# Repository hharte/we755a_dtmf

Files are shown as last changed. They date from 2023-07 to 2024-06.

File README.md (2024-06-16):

# WE 755A PBX DTMF Converter

# Introduction

The Western Electric 755A PBX was designed in 1938 and supports pulse dialing only  This DTMF converter adds support for Touch-Tone dialing.  One DTMF Converter board needs to be installed in each of the three links.  The converter recognizes DTMF digits, and sets the pulse counting relays in the link to the terminal count for the number dialed.  This is not a tone to pulse converter, and operates much faster than one.

The dial plan for the 755A PBX consists of local station extensions 20-29 and 30-39.  Although this PBX supports four trunks, they are not directly accessible by stations; instead, key stations with individual trunk pickup keys are used to select the trunks.

Here is an [introductory video of the 755A PBX in operation](https://www.youtube.com/watch?v=Fxt21lnzOqg).

This project builds upon the [OKI AC125A DTMF Converter](https://github.com/hharte/ac125a_dtmf) designed several years ago.  While the OKI is an electromechanical crossbar PBX similar in some ways to the 755A, the OKI is about 40 years more modern.

# Status

Three boards have been assembled and installed in each of the 755A’s links.  They work as intended for station to station and conference calls.

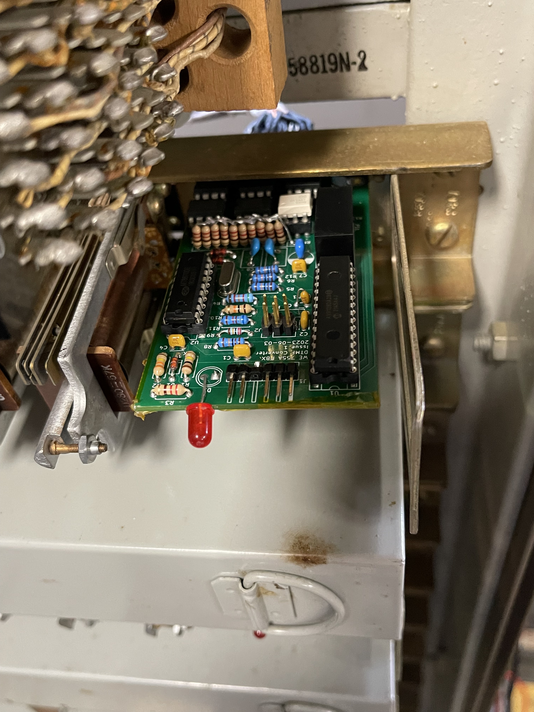
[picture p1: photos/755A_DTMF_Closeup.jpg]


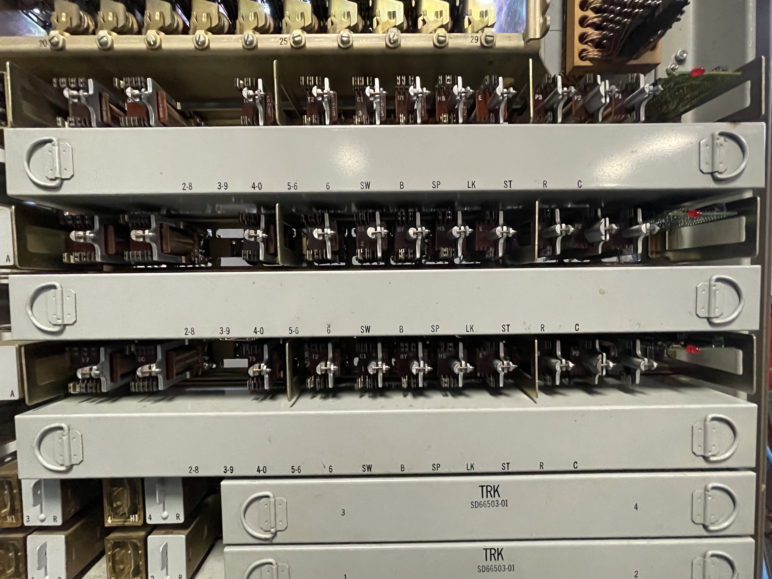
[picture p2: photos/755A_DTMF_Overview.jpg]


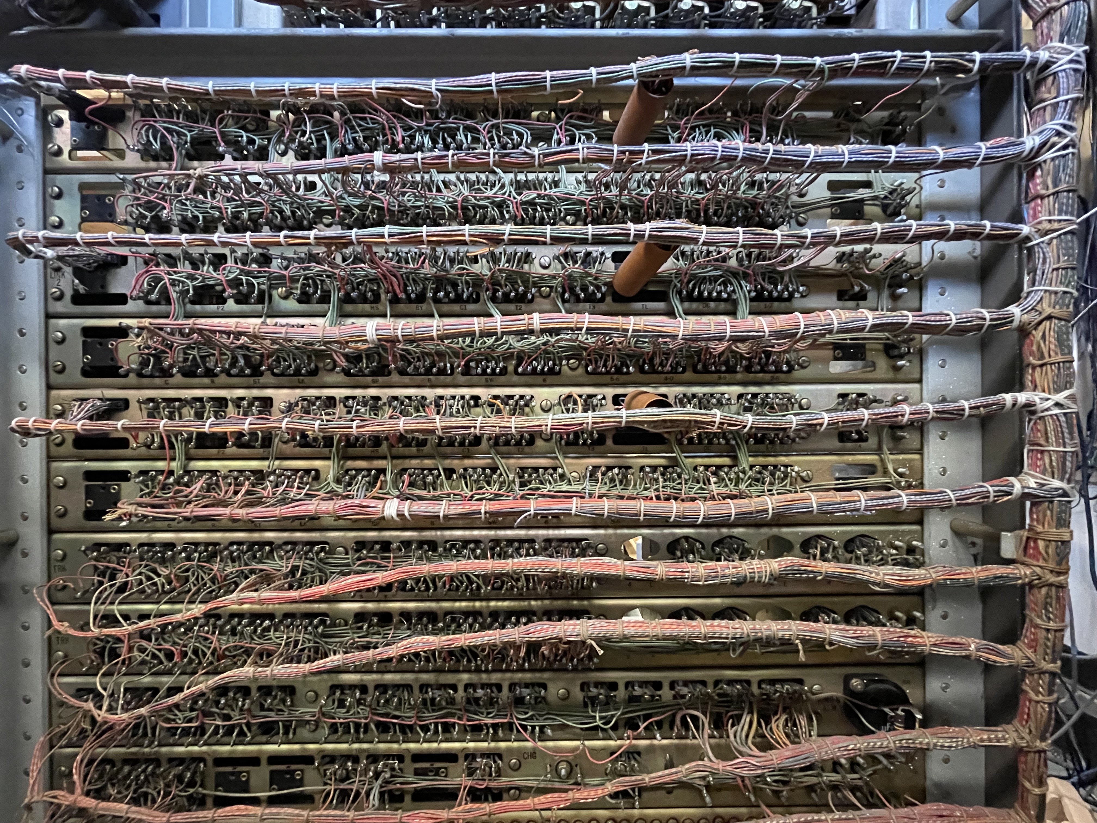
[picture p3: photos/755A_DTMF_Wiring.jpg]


# Translation

The DTMF converter employs digit translation as follows:

<table>
  <tr>
   <td>First Dialed Digit
   </td>
   <td>755A Extension
   </td>
   <td>Description
   </td>
  </tr>
  <tr>
   <td>0
   </td>
   <td>20
   </td>
   <td>Operator
   </td>
  </tr>
  <tr>
   <td>1
   </td>
   <td>-
   </td>
   <td>No operation
   </td>
  </tr>
  <tr>
   <td>2
   </td>
   <td>2x
   </td>
   <td>Direct-dialed 755A stations.
   </td>
  </tr>
  <tr>
   <td>3
   </td>
   <td>3x
   </td>
   <td>Direct-dialed 755A stations.
   </td>
  </tr>
  <tr>
   <td>4, 5, 6, 7
   </td>
   <td>-
   </td>
   <td>No operation
   </td>
  </tr>
  <tr>
   <td>8
   </td>
   <td>26
   </td>
   <td>Ringdown extensions 26, 27.
   </td>
  </tr>
  <tr>
   <td>9
   </td>
   <td>36
   </td>
   <td>Ringdown extensions 36, 37
   </td>
  </tr>
</table>

# 755A PBX Connector

<table>
  <tr>
   <td>Pin
   </td>
   <td>Description
   </td>
   <td>Ribbon Cable Color
   </td>
   <td>Cloth Wire Color
   </td>
   <td>755A Link Connection
   </td>
  </tr>
  <tr>
   <td>1,2
   </td>
   <td>GRD
   </td>
   <td>Brown/Red
   </td>
   <td>Black
   </td>
   <td>Connect to the B relay coil so the converter powers up when the link is active.
   </td>
  </tr>
  <tr>
   <td>3
   </td>
   <td>LINK_SPARE
   </td>
   <td>Orange
   </td>
   <td>
   </td>
   <td>
   </td>
  </tr>
  <tr>
   <td>4
   </td>
   <td>LINK_C1
   </td>
   <td>Yellow
   </td>
   <td>Or/Sl
   </td>
   <td>
   </td>
  </tr>
  <tr>
   <td>5
   </td>
   <td>LINK_6
   </td>
   <td>Green
   </td>
   <td>Sl/W/R
   </td>
   <td>
   </td>
  </tr>
  <tr>
   <td>6
   </td>
   <td>LINK_5-6
   </td>
   <td>Blue
   </td>
   <td>SL/W
   </td>
   <td>
   </td>
  </tr>
  <tr>
   <td>7
   </td>
   <td>LINK_4-0
   </td>
   <td>Violet
   </td>
   <td>Br/R
   </td>
   <td>
   </td>
  </tr>
  <tr>
   <td>8
   </td>
   <td>LINK_3-9
   </td>
   <td>Slate
   </td>
   <td>Br
   </td>
   <td>
   </td>
  </tr>
  <tr>
   <td>9
   </td>
   <td>LINK_2-8
   </td>
   <td>White
   </td>
   <td>Gr/R
   </td>
   <td>
   </td>
  </tr>
  <tr>
   <td>10
   </td>
   <td>LINK_1-7
   </td>
   <td>Black
   </td>
   <td>Gr
   </td>
   <td>
   </td>
  </tr>
  <tr>
   <td>11
   </td>
   <td>LINK_T3
   </td>
   <td>Brown
   </td>
   <td>Or/R
   </td>
   <td>
   </td>
  </tr>
  <tr>
   <td>12
   </td>
   <td>LINK_T2
   </td>
   <td>Red
   </td>
   <td>Or
   </td>
   <td>
   </td>
  </tr>
  <tr>
   <td>13
   </td>
   <td>N/C
   </td>
   <td>Orange
   </td>
   <td>
   </td>
   <td>
   </td>
  </tr>
  <tr>
   <td>14
   </td>
   <td>N/C
   </td>
   <td>Yellow
   </td>
   <td>
   </td>
   <td>
   </td>
  </tr>
  <tr>
   <td>15
   </td>
   <td>N/C
   </td>
   <td>Green
   </td>
   <td>
   </td>
   <td>
   </td>
  </tr>
  <tr>
   <td>16
   </td>
   <td>LINK_E
   </td>
   <td>Blue
   </td>
   <td>Blue
   </td>
   <td>
   </td>
  </tr>
  <tr>
   <td>17
   </td>
   <td>Tip
   </td>
   <td>Violet
   </td>
   <td>O/GR
   </td>
   <td>
   </td>
  </tr>
  <tr>
   <td>18
   </td>
   <td>Ring
   </td>
   <td>Slate
   </td>
   <td>O/GR-R
   </td>
   <td>
   </td>
  </tr>
  <tr>
   <td>19,20
   </td>
   <td>-24VDC
   </td>
   <td>White/Black
   </td>
   <td>Red
   </td>
   <td>-24VDC (Red)
   </td>
  </tr>
</table>

# Connection Notes

From SD-66611-01:

-BAT: Pick up from P1 relay red lead.

GRD: Pick up from B relay coil.

LINK_B: (Blue) Pick up from B relay coil (Upper left terminal.)

Tip: (Violet): Pick up T from 2mF capacitors on lower right corner (looking at from rear):

Ring: (Slate): Pick up T from 2mF capacitors on lower right corner (looking at from rear):

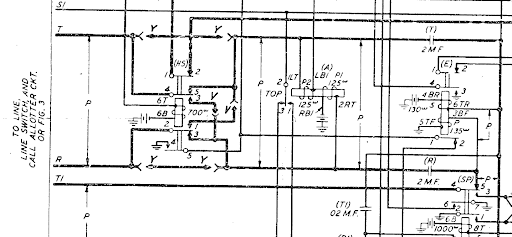
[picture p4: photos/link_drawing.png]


LINK_T2: (Red) Pick up from T2 relay coil.

LINK_T3: (Brown) Pick up from T3 relay coil.

LINK_C1: (Yellow) Pick up from C1 relay coil.

# Technical Details

## Theory of Operation

The 755A DTMF converter’s ground supply is connected to the B relay coil in the link so that the DTMF converter is only powered on when the link is active.  This is necessary so that the first and second digits dialed can be properly identified if the calling station hangs up after dialing only a single digit.

When a station goes off hook, the link allotter selects an idle link, operating the link’s B relay.  This powers up the DTMF converter, which waits for digit(s) to be dialed.  If the first dialed digit is 2 or 3, the converter waits for a second digit to be dialed and then activates the tens and units counting relays to their terminal count.  If the first digit is a digit other than 2 or 3 is dialed, the digit is handled as follows:

* 1, 4, 5, 6, or 7: Ignored
* 0, 8, 9: Translated to a 2-digit extension that is dialed immediately.

After dialing is complete, further dialing is disabled until the called station answers and hangs up again.  This is needed to prevent operation of the pulse counting relays during an established call, while also supporting conference calling.

Conference calling with the 755A works as follows:

1. The originating station calls an extension.
2. The extension answers the call, activating the E relay.
3. The originating station asks the answering station to hang up momentarily so that a conference call can be established.
4. After the called station hangs up, the originating station dials the number of an additional station to join the conference.
5. After the first digit of the called number is dialed, 

## Pulse Dialing Terminal Count Relays

### Tens Digit (2 or 3)

<table>
  <tr>
   <td>Digit
   </td>
   <td>Relays Activated
   </td>
   <td>Note
   </td>
  </tr>
  <tr>
   <td>2
   </td>
   <td>T2
   </td>
   <td>T2 activated stops dialtone.
   </td>
  </tr>
  <tr>
   <td>3
   </td>
   <td>T2 and T3
   </td>
   <td>
   </td>
  </tr>
</table>

### Units Digit (0-9)

<table>
  <tr>
   <td>Digit
   </td>
   <td>Relays Activated
   </td>
   <td>To finish dialing
   </td>
  </tr>
  <tr>
   <td>1
   </td>
   <td>C1, 1-7
   </td>
   <td>Release C1
   </td>
  </tr>
  <tr>
   <td>2
   </td>
   <td>C1, 2-8
   </td>
   <td>Release C1
   </td>
  </tr>
  <tr>
   <td>3
   </td>
   <td>C1, 3-9
   </td>
   <td>Release C1
   </td>
  </tr>
  <tr>
   <td>4
   </td>
   <td>C1, 4-0
   </td>
   <td>Release C1
   </td>
  </tr>
  <tr>
   <td>5
   </td>
   <td>C1, 5-6
   </td>
   <td>Release C1
   </td>
  </tr>
  <tr>
   <td>6
   </td>
   <td>C1, 5-6, 6
   </td>
   <td>Release C1
   </td>
  </tr>
  <tr>
   <td>7
   </td>
   <td>C1, 1-7, 6
   </td>
   <td>Release C1
   </td>
  </tr>
  <tr>
   <td>8
   </td>
   <td>C1, 2-8, 6
   </td>
   <td>Release C1
   </td>
  </tr>
  <tr>
   <td>9
   </td>
   <td>C1, 3-9, 6
   </td>
   <td>Release C1
   </td>
  </tr>
  <tr>
   <td>0
   </td>
   <td>C1, 4-0, 6
   </td>
   <td>Release C1
   </td>
  </tr>
</table>

## Inputs from 755A

<table>
  <tr>
   <td>T
   </td>
   <td colspan="3" >Tip
   </td>
  </tr>
  <tr>
   <td>R
   </td>
   <td colspan="3" >Ring
   </td>
  </tr>
  <tr>
   <td>E
   </td>
   <td colspan="3" >Call Active (Interrupt the microcontroller.)
   </td>
  </tr>
</table>

## Outputs to 755A

<table>
  <tr>
   <td>T2
   </td>
   <td colspan="3" >Tens Digit 2 (Breaks dial tone.)
   </td>
  </tr>
  <tr>
   <td>T3
   </td>
   <td colspan="3" >Tens Digit 3 (Also requires T2 activated.)
   </td>
  </tr>
  <tr>
   <td>1-7, 2-8, 3-9, 4-0, 5-6, 6
   </td>
   <td colspan="3" >Units Digit Selection
   </td>
  </tr>
  <tr>
   <td>C1
   </td>
   <td colspan="3" >Activated before Units selection relays are set, released when the digit is complete.
   </td>
  </tr>
</table>

## MT8870 DTMF Converter Outputs

<table>
  <tr>
   <td>Q3:0
   </td>
   <td colspan="3" >DTMF Digit Selection
   </td>
  </tr>
  <tr>
   <td>StB
   </td>
   <td colspan="3" >DTMF Valid Strobe (Interrupt to microcontroller.)
   </td>
  </tr>
</table>

## Bill of Materials

Online [DigiKey BOM](https://www.digikey.com/en/mylists/list/MP3JW7CHBF).  [Interactive BOM](https://html-preview.github.io/?url=https://github.com/hharte/we755a_dtmf/blob/main/hardware/bom/ibom.html).

<table>
  <tr>
   <td>Quantity
   </td>
   <td>Reference Designator
   </td>
   <td>Value
   </td>
  </tr>
  <tr>
   <td>4
   </td>
   <td>C1, C2, C4, C7
   </td>
   <td>0.1uF
   </td>
  </tr>
  <tr>
   <td>1
   </td>
   <td>C3
   </td>
   <td>0.01uF
   </td>
  </tr>
  <tr>
   <td>2
   </td>
   <td>C5, C8
   </td>
   <td>0.01uF/630V
   </td>
  </tr>
  <tr>
   <td>1
   </td>
   <td>C6
   </td>
   <td>10uF 25V
   </td>
  </tr>
  <tr>
   <td>1
   </td>
   <td>D1
   </td>
   <td>1N4148
   </td>
  </tr>
  <tr>
   <td>1
   </td>
   <td>D2
   </td>
   <td>LED
   </td>
  </tr>
  <tr>
   <td>2
   </td>
   <td>D3, D4
   </td>
   <td>1N4734A
   </td>
  </tr>
  <tr>
   <td>2
   </td>
   <td>F1, F2
   </td>
   <td>Fuse 630mA
   </td>
  </tr>
  <tr>
   <td>2
   </td>
   <td>H1, H2
   </td>
   <td>MountingHole
   </td>
  </tr>
  <tr>
   <td>1
   </td>
   <td>J1
   </td>
   <td>Conn_01x06_Male right angle
   </td>
  </tr>
  <tr>
   <td>1
   </td>
   <td>J2
   </td>
   <td>UPDI (2x3 pin header) Straight
   </td>
  </tr>
  <tr>
   <td>1
   </td>
   <td>J3
   </td>
   <td>Conn_02x10_Odd_Even
   </td>
  </tr>
  <tr>
   <td>1
   </td>
   <td>PS1
   </td>
   <td>SPBW06
   </td>
  </tr>
  <tr>
   <td>1
   </td>
   <td>R1
   </td>
   <td>100K
   </td>
  </tr>
  <tr>
   <td>1
   </td>
   <td>R2
   </td>
   <td>330K
   </td>
  </tr>
  <tr>
   <td>1
   </td>
   <td>R3
   </td>
   <td>220
   </td>
  </tr>
  <tr>
   <td>1
   </td>
   <td>R4
   </td>
   <td>52.3K 1%
   </td>
  </tr>
  <tr>
   <td>4
   </td>
   <td>R5, R6, R8, R12
   </td>
   <td>110K 1%
   </td>
  </tr>
  <tr>
   <td>1
   </td>
   <td>R7
   </td>
   <td>4.7K
   </td>
  </tr>
  <tr>
   <td>1
   </td>
   <td>R9
   </td>
   <td>220K 1%
   </td>
  </tr>
  <tr>
   <td>1
   </td>
   <td>R10
   </td>
   <td>10K
   </td>
  </tr>
  <tr>
   <td>1
   </td>
   <td>R11
   </td>
   <td>68.1K 1%
   </td>
  </tr>
  <tr>
   <td>1
   </td>
   <td>R13
   </td>
   <td>1.5K
   </td>
  </tr>
  <tr>
   <td>1
   </td>
   <td>RN1
   </td>
   <td>220
   </td>
  </tr>
  <tr>
   <td>1
   </td>
   <td>U1
   </td>
   <td>AVR128DA28-I/SP or AVR128DA28-E/SP
   </td>
  </tr>
  <tr>
   <td>1
   </td>
   <td>U2
   </td>
   <td>MT8870
   </td>
  </tr>
  <tr>
   <td>1
   </td>
   <td>U3
   </td>
   <td>H11AA1
   </td>
  </tr>
  <tr>
   <td>5
   </td>
   <td>U4, U5, U6, U7, U8
   </td>
   <td>LAA108 (or LAA110L or CLA170)
   </td>
  </tr>
  <tr>
   <td>1
   </td>
   <td>Y2
   </td>
   <td>3.579545MHZ
   </td>
  </tr>
</table>

## Arduino AVD128DA28 Configuration

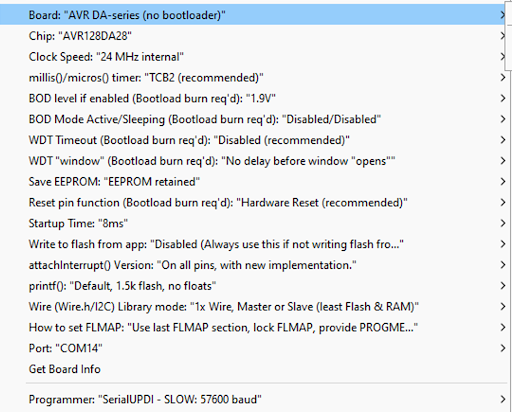
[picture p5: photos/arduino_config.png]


# Other WE 755A Projects

[WE 755A Power Supply](https://github.com/hharte/we755a_ps)

[WE 755A Station Line Concentrator](https://github.com/hharte/we755a_slc)

[WE 755A PBX Monitor](https://github.com/hharte/we755a_mon)

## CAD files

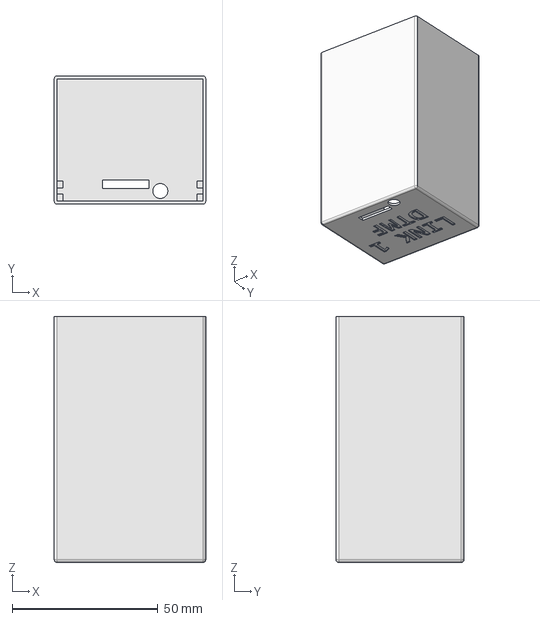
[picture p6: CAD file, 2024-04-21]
enclosure/we755a_dtmf_cover.FCStd
52.0 x 44.0 x 84.4 mm

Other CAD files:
enclosure/we755a_dtmf_cover.stl

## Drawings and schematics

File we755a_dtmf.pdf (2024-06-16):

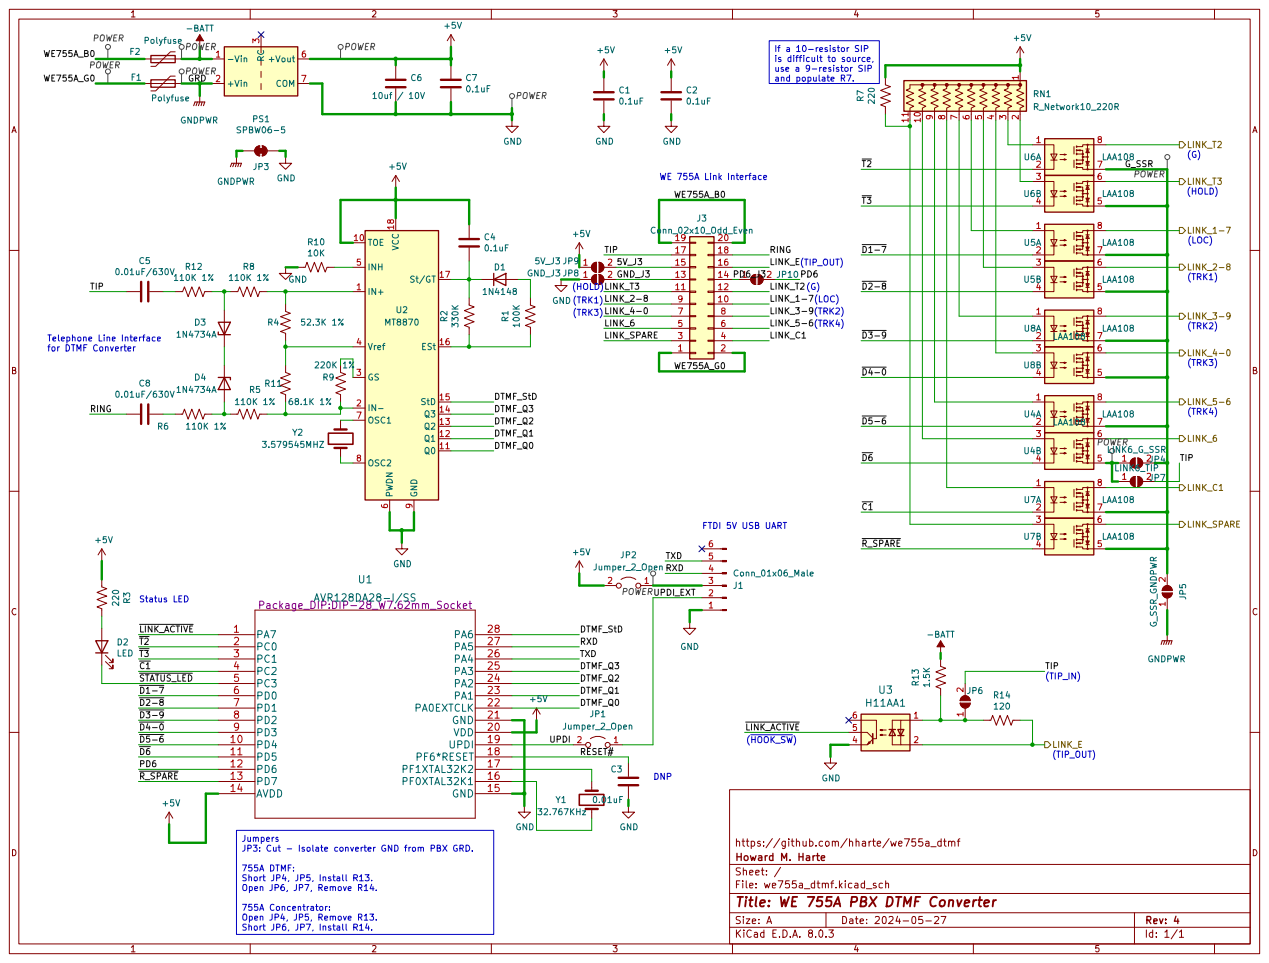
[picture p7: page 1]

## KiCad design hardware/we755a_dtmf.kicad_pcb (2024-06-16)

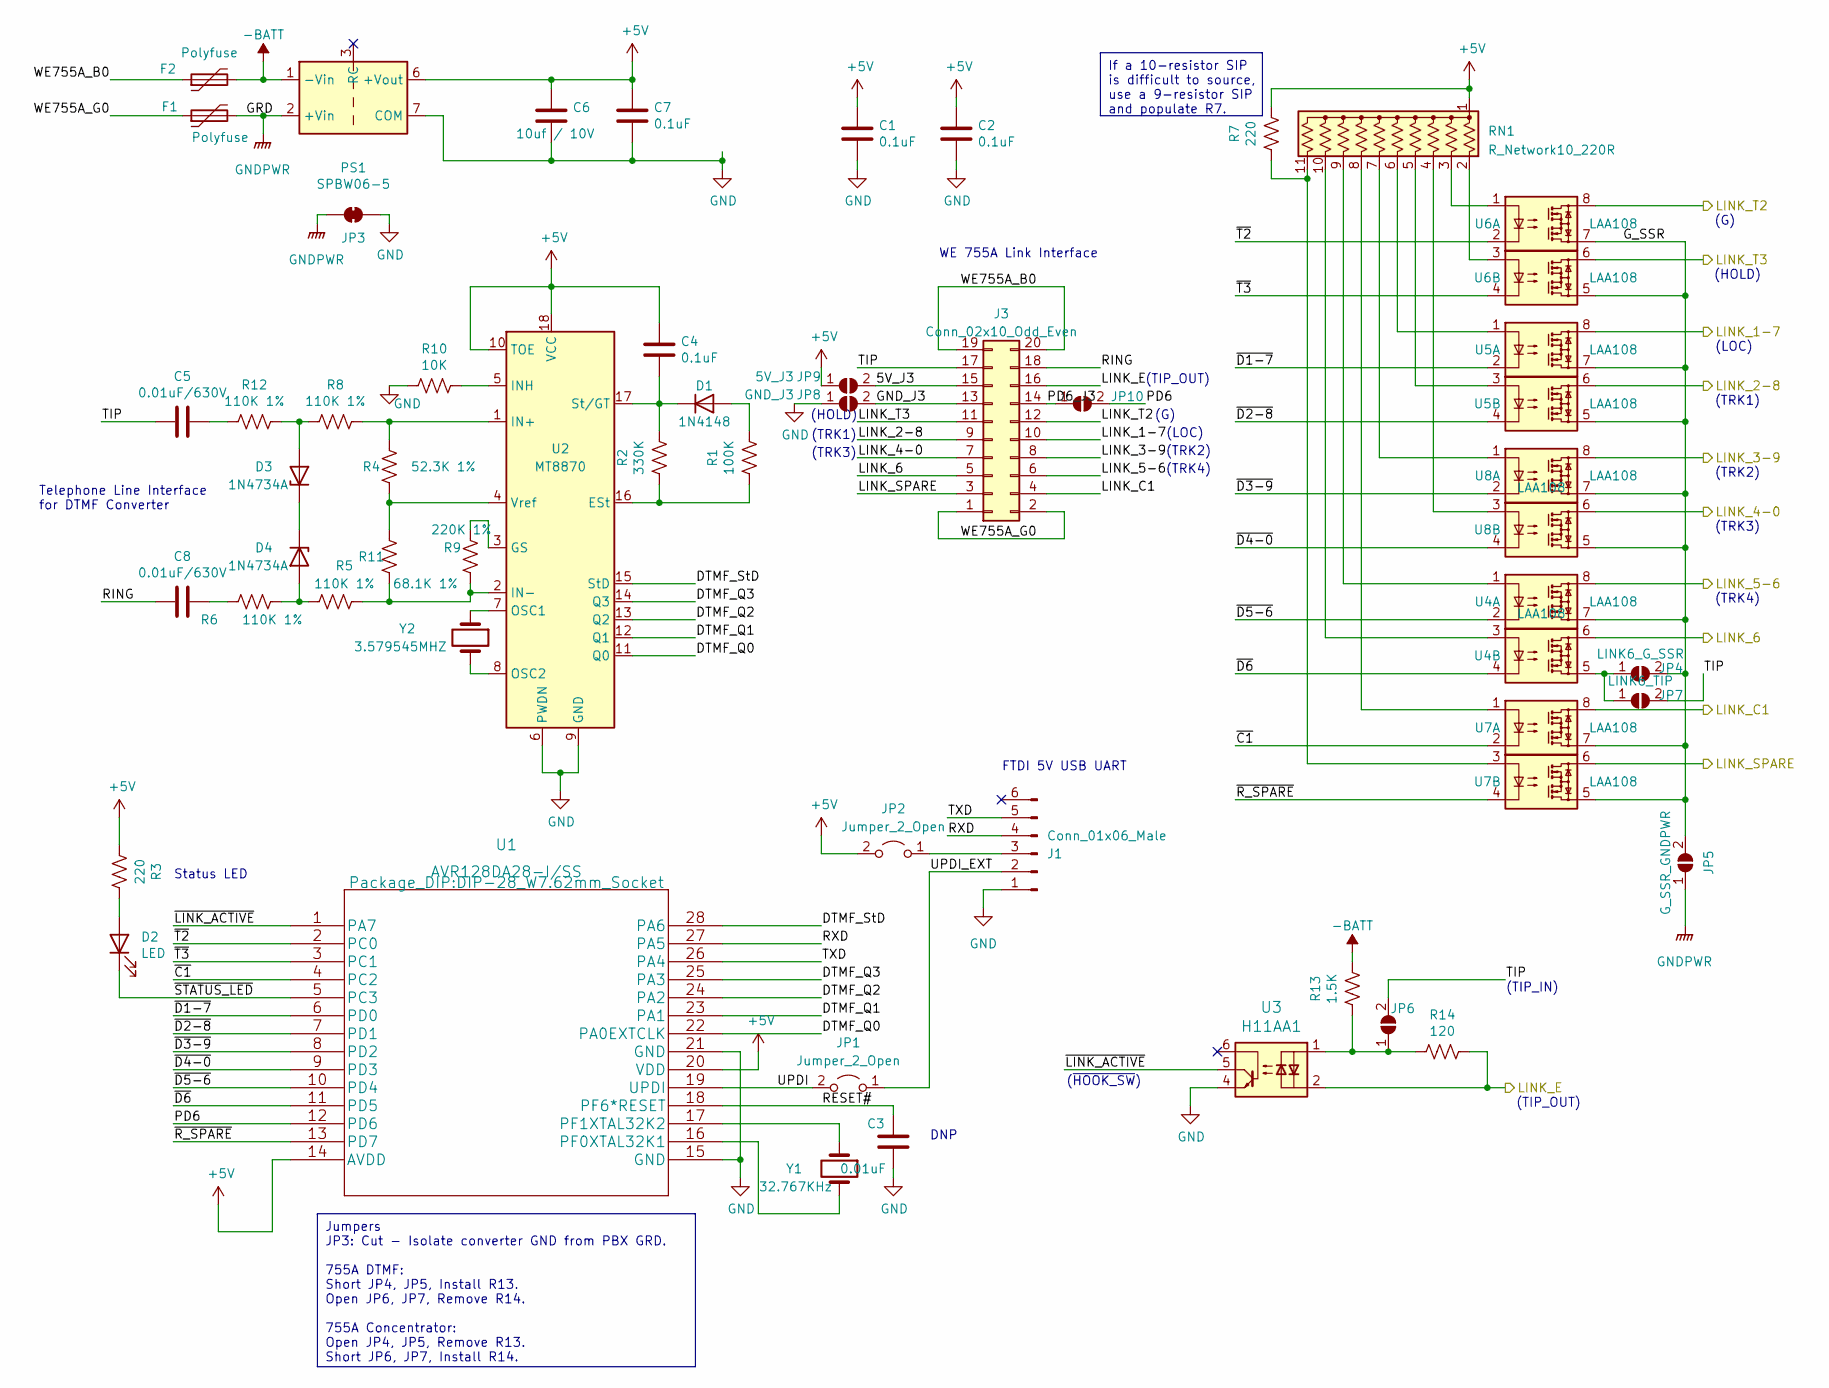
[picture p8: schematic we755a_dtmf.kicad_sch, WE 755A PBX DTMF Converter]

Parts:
C1, C2, C4, C7: 0.1uF; C_Disc_D3.0mm_W2.0mm_P2.50mm; MPN K104M15X7RF5TL2; Digi-Key_PN 56-K104M15X7RF5TL2CT-ND
C3: 0.01uF; C_Disc_D3.0mm_W1.6mm_P2.50mm; MPN K103K15X7RF5UL2; Digi-Key_PN BC5227CT-ND
C5, C8: 0.01uF/630V; C_Disc_D7.5mm_W5.0mm_P5.00mm; MPN RDER72J103K2K1H03B; Digi-Key_PN 490-8927-ND
C6: 10uf / 10V; C_Disc_D5.0mm_W2.5mm_P2.50mm; MPN FG14X7R1A106KRT06; Digi-Key_PN 445-173132-1-ND
D1: 1N4148; D_DO-35_SOD27_P7.62mm_Horizontal; MPN 1N4148TA; Digi-Key_PN 1N4148TACT-ND
D2: LED; LED_D5.0mm; MPN XLUR12D; Digi-Key_PN 1497-1031-ND
D3, D4: 1N4734A; D_DO-41_SOD81_P7.62mm_Horizontal; MPN 1N4734A-T50A; Digi-Key_PN 1N4734A-T50ACT-ND
F1, F2: Polyfuse; FUSE_RXEF025_LTF; MPN RXEF025; Digi-Key_PN RXEF025HF-ND
J1: Conn_01x06_Male; PinHeader_1x06_P2.54mm_Horizontal; MPN 61300611021; Digi-Key_PN 732-5339-ND
J3: Conn_02x10_Odd_Even; WE755A-DTMF; MPN SBH11-PBPC-D10-RA-BK; Digi-Key_PN S9180-ND
JP1, JP2: Jumper_2_Open; PinHeader_1x02_P2.54mm_Vertical
JP3: GRD_TIE; SolderJumper-2_P1.3mm_Bridged_Pad1.0x1.5mm
JP4: LINK6_G_SSR; SolderJumper-2_P1.3mm_Open_Pad1.0x1.5mm
JP5: G_SSR_GNDPWR; SolderJumper-2_P1.3mm_Open_Pad1.0x1.5mm
JP6: TIP_IN; SolderJumper-2_P1.3mm_Open_Pad1.0x1.5mm
JP7: LINK6_TIP; SolderJumper-2_P1.3mm_Open_Pad1.0x1.5mm
JP8: GND_J3; SolderJumper-2_P1.3mm_Open_Pad1.0x1.5mm
JP9, JP10: 5V_J3; SolderJumper-2_P1.3mm_Open_Pad1.0x1.5mm
PS1: SPBW06-5; Converter_DCDC_TRACO_TMR-xxxx_THT; MPN SPBW06G-05; Digi-Key_PN 1866-4814-ND
R1: 100K; R_Axial_DIN0207_L6.3mm_D2.5mm_P7.62mm_Horizontal; MPN CFM12JT100K; Digi-Key_PN S100KHCT-ND
R2: 330K; R_Axial_DIN0207_L6.3mm_D2.5mm_P7.62mm_Horizontal; MPN CFM12JT330K; Digi-Key_PN S330KHCT-ND
R3: 220; R_Axial_DIN0207_L6.3mm_D2.5mm_P7.62mm_Horizontal; MPN CFM14JT220R; Digi-Key_PN S220QCT-ND
R4: 52.3K 1%; R_Axial_DIN0207_L6.3mm_D2.5mm_P7.62mm_Horizontal; MPN MFR-25FBF52-52K3; Digi-Key_PN 52.3KXBK-ND
R5, R6, R8, R12: 110K 1%; R_Axial_DIN0207_L6.3mm_D2.5mm_P7.62mm_Horizontal; MPN MFR-25FBF52-110K; Digi-Key_PN 110KXBK-ND
R7: 220; R_Axial_DIN0204_L3.6mm_D1.6mm_P5.08mm_Horizontal; MPN CFM14JT220R; Digi-Key_PN S220QCT-ND
R9: 220K 1%; R_Axial_DIN0207_L6.3mm_D2.5mm_P7.62mm_Horizontal; MPN MFR-25FBF52-220K; Digi-Key_PN MFR-25FBF52-220K-ND
R10: 10K; R_Axial_DIN0207_L6.3mm_D2.5mm_P7.62mm_Horizontal; MPN CFM12JT10K0; Digi-Key_PN S10KHCT-ND
R11: 68.1K 1%; R_Axial_DIN0207_L6.3mm_D2.5mm_P7.62mm_Horizontal; MPN MFR-25FBF52-68K1; Digi-Key_PN 68.1KXBK-ND
R13: 1.5K; R_Axial_DIN0207_L6.3mm_D2.5mm_P7.62mm_Horizontal; MPN CFM12JT1K50; Digi-Key_PN S1.5KHCT-ND
R14: 120; R_Axial_DIN0207_L6.3mm_D2.5mm_P7.62mm_Horizontal; MPN CFM12JT120R; Digi-Key_PN S120HCT-ND
RN1: R_Network10_220R; R_Array_SIP11; MPN 4611X-101-221LF; Digi-Key_PN 118-4611X-101-221LF-ND
U1: AVR128DA28-I/SS; DIP-28_W7.62mm_Socket; MPN AVR128DA28-E/SP; Digi-Key_PN 150-AVR128DA28-E/SP-ND
U2: MT8870; DIP-18_W7.62mm
U3: H11AA1; DIP-6_W7.62mm; MPN H11AA1; Digi-Key_PN H11AA1M-ND
U4, U5, U6, U7, U8: LAA108; DIP-8_W7.62mm; MPN LAA108; Digi-Key_PN LAA108-ND
Y1: 32.767KHz; Crystal_Round_D2.0mm_Vertical; MPN Do not populate.; Digi-Key_PN Do not populate.
Y2: 3.579545MHZ; Crystal_HC49-U_Vertical; MPN 9B-3.579545MAAJ-B; Digi-Key_PN 887-1000-ND

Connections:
+5V: C1.1, C2.1, C4.2, C6.1, C7.1, JP2.2 (B), JP9.1 (A), PS1.6 (+Vout), R3.2, R7.1, RN1.1 (common), U1.14 (AVDD), U1.20 (VDD), U2.10 (TOE), U2.18 (VCC)
-BATT: F2.2, PS1.1 (-Vin), R13.1
/5V_J3: J3.15, JP9.2 (B)
/DTMF_Q0: U1.22 (PA0EXTCLK), U2.11 (Q0)
/DTMF_Q1: U1.23 (PA1), U2.12 (Q1)
/DTMF_Q2: U1.24 (PA2), U2.13 (Q2)
/DTMF_Q3: U1.25 (PA3), U2.14 (Q3)
/DTMF_StD: U1.28 (PA6), U2.15 (StD)
/GND_J3: J3.13, JP8.2 (B)
/G_SSR: JP4.2 (B), JP5.2 (B), U4.7, U5.5, U5.7, U6.5, U6.7, U7.5, U7.7, U8.5, U8.7
/LINK_1-7: J3.10, U5.8
/LINK_2-8: J3.9, U5.6
/LINK_3-9: J3.8, U8.8
/LINK_4-0: J3.7, U8.6
/LINK_5-6: J3.6, U4.8
/LINK_6: J3.5, U4.6
/LINK_C1: J3.4, U7.8
/LINK_E: J3.16, R14.1, U3.2
/LINK_SPARE: J3.3, U7.6
/LINK_T2: J3.12, U6.8
/LINK_T3: J3.11, U6.6
/PD6: JP10.2 (B), U1.12 (PD6)
/PD6_J3: J3.14, JP10.1 (A)
/RESET#: C3.1, U1.18 (PF6*RESET)
/RING: C8.2, J3.18
/RXD: J1.4, U1.27 (PA5)
/TIP: C5.2, J3.17, JP6.2 (B), JP7.2 (B)
/TXD: J1.5, U1.26 (PA4)
/UPDI: JP1.2 (B), U1.19 (UPDI)
/UPDI_EXT: J1.2, JP1.1 (A)
/WE755A_B0: F2.1, J3.19, J3.20
/WE755A_G0: F1.1, J3.1, J3.2
/~C1: U1.4 (PC2), U7.2
/~D1-7: U1.6 (PD0), U5.2
/~D2-8: U1.7 (PD1), U5.4
/~D3-9: U1.8 (PD2), U8.2
/~D4-0: U1.9 (PD3), U8.4
/~D5-6: U1.10 (PD4), U4.2
/~D6: U1.11 (PD5), U4.4
/~LINK_ACTIVE: U1.1 (PA7), U3.5
/~R_SPARE: U1.13 (PD7), U7.4
/~STATUS_LED: D2.1 (K), U1.5 (PC3)
/~T2: U1.2 (PC0), U6.2
/~T3: U1.3 (PC1), U6.4
GND: C1.2, C2.2, C3.2, C6.2, C7.2, J1.1, JP3.2 (B), JP8.1 (A), PS1.7 (COM), R10.2, U1.15 (GND), U1.21 (GND), U2.6 (PWDN), U2.9 (GND), U3.4
GNDPWR: F1.2, JP3.1 (A), JP5.1 (A), PS1.2 (+Vin)
unnamed: C5.1, R12.2
unnamed: C8.1, R6.2
unnamed: D1.2 (A), R1.1
unnamed: C4.1, D1.1 (K), R2.1, U2.17 (St/GT)
unnamed: D2.2 (A), R3.1
unnamed: D3.2 (A), R8.2, R12.1
unnamed: D3.1 (K), D4.1 (K)
unnamed: D4.2 (A), R5.2, R6.1
unnamed: J1.3, JP2.1 (A)
unnamed: JP4.1 (A), JP7.1 (A), U4.5
unnamed: JP6.1 (A), R13.2, R14.2, U3.1
unnamed: RN1.2 (R1), U6.3
unnamed: RN1.3 (R2), U6.1
unnamed: RN1.4 (R3), U8.3
unnamed: RN1.5 (R4), U5.3
unnamed: RN1.6 (R5), U5.1
unnamed: RN1.7 (R6), U8.1
unnamed: RN1.8 (R7), U7.1
unnamed: RN1.9 (R8), U4.1
unnamed: RN1.10 (R9), U4.3
unnamed: R7.2, RN1.11 (R10), U7.3
unnamed: U1.16 (PF0XTAL32K1), Y1.2
unnamed: U1.17 (PF1XTAL32K2), Y1.1
unnamed: R1.2, R2.2, U2.16 (ESt)
unnamed: R9.1, U2.3 (GS)
unnamed: R4.1, R8.1, U2.1 (IN+)
unnamed: R5.1, R9.2, R11.2, U2.2 (IN-)
unnamed: R10.1, U2.5 (INH)
unnamed: U2.7 (OSC1), Y2.1
unnamed: U2.8 (OSC2), Y2.2
unnamed: R4.2, R11.1, U2.4 (Vref)

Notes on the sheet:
If a 10-resistor SIP is difficult to source, use a 9-resistor SIP and populate R7.
Jumpers JP3: Cut - Isolate converter GND from PBX GRD. 755A DTMF: Short JP4, JP5, Install R13. Open JP6, JP7, Remove R14. 755A Concentrator: Open JP4, JP5, Remove R13. Short JP6, JP7, Install R14.
(HOLD)
FTDI 5V USB UART
Status LED
(~{HOOK_SW})
(TIP_OUT)
(TRK2)
(TRK4)
WE 755A Link Interface
(TIP_IN)
(G)
(TRK1)
DNP
Telephone Line Interface for DTMF Converter
(LOC)
(TRK3)

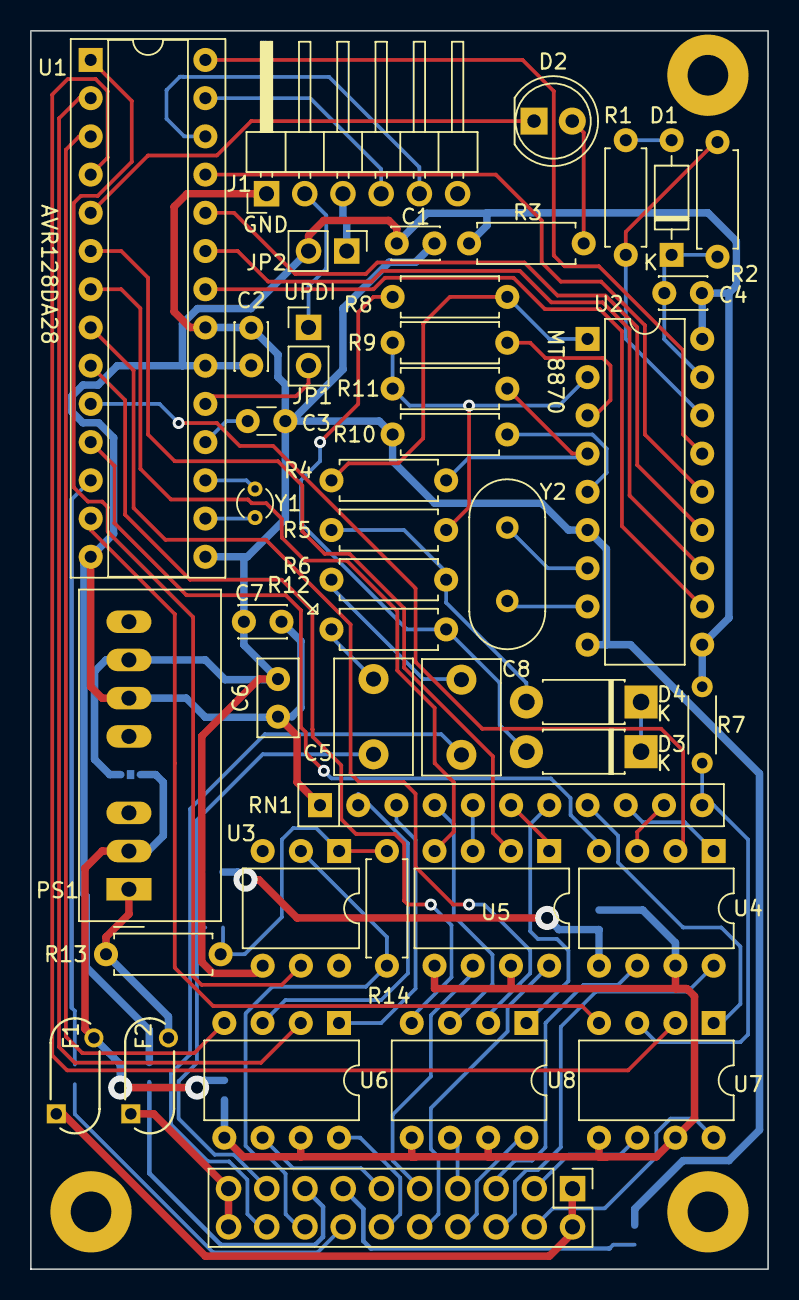
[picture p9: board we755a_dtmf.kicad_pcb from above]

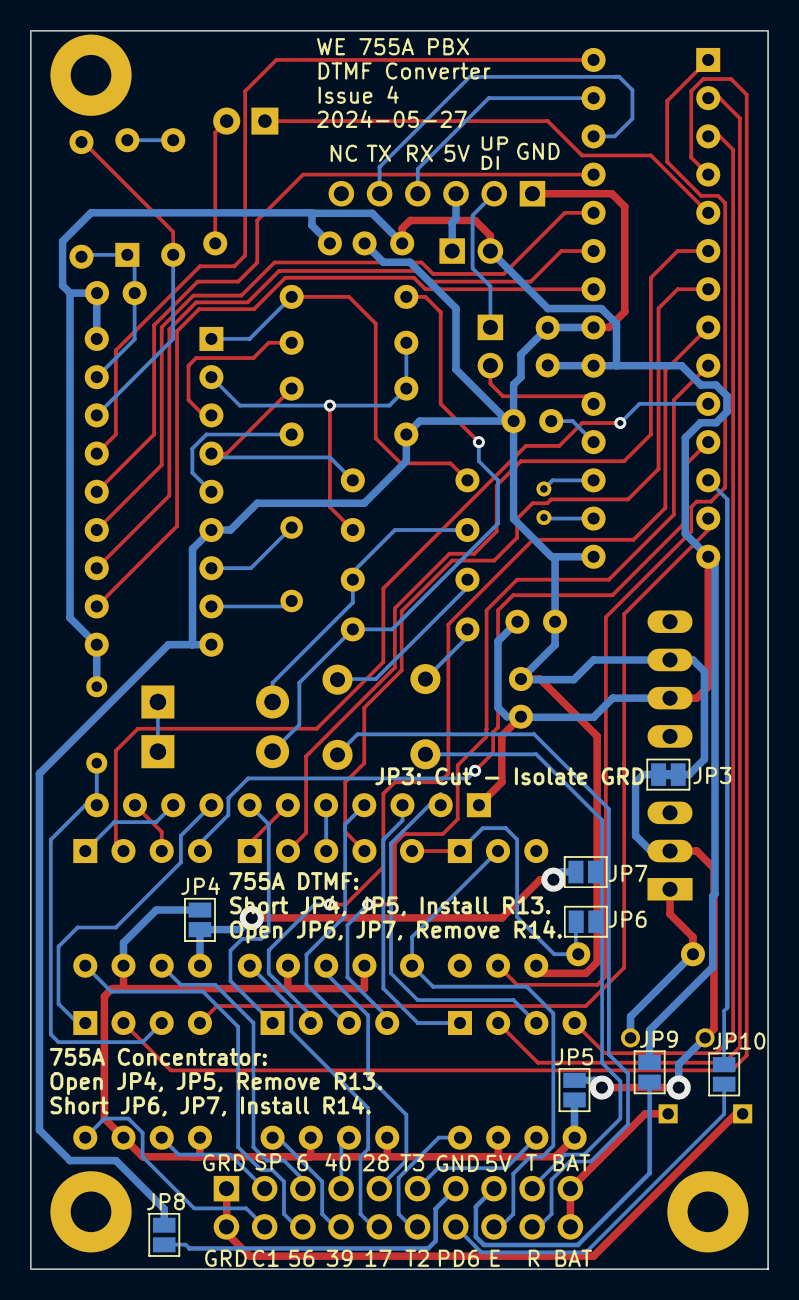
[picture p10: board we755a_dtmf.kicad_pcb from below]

Board: 2 copper layers, 49.0 x 82.3 mm, 52 parts (8 on the bottom side), 77 nets.

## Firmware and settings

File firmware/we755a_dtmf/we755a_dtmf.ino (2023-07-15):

/*************************************************************************
 *                                                                       *
 * Copyright (c) 2023 Howard M. Harte, WZ2Q.                             *
 * https://github.com/hharte/we755a_dtmf                                 *
 *                                                                       *
 * Permission is hereby granted, free of charge, to any person obtaining *
 * a copy of this software and associated documentation files (the       *
 * "Software"), to deal in the Software without restriction, including   *
 * without limitation the rights to use, copy, modify, merge, publish,   *
 * distribute, sublicense, and/or sell copies of the Software, and to    *
 * permit persons to whom the Software is furnished to do so, subject to *
 * the following conditions:                                             *
 *                                                                       *
 * The above copyright notice and this permission notice shall be        *
 * included in all copies or substantial portions of the Software.       *
 *                                                                       *
 * THE SOFTWARE IS PROVIDED "AS IS", WITHOUT WARRANTY OF ANY KIND,       *
 * EXPRESS OR IMPLIED, INCLUDING BUT NOT LIMITED TO THE WARRANTIES OF    *
 * MERCHANTABILITY, FITNESS FOR A PARTICULAR PURPOSE AND                 *
 * NONINFRINGEMENT. IN NO EVENT SHALL HOWARD M. HARTE BE LIABLE FOR ANY  *
 * CLAIM, DAMAGES OR OTHER LIABILITY, WHETHER IN AN ACTION OF CONTRACT,  *
 * TORT OR OTHERWISE, ARISING FROM, OUT OF OR IN CONNECTION WITH THE     *
 * SOFTWARE OR THE USE OR OTHER DEALINGS IN THE SOFTWARE.                *
 *                                                                       *
 * Except as contained in this notice, the name of Howard M. Harte shall *
 * not be used in advertising or otherwise to promote the sale, use or   *
 * other dealings in this Software without prior written authorization   *
 * Howard M. Harte.                                                      *
 *                                                                       *
 * Module Description:                                                   *
 * Western Electric 755A Crossbar PBX DTMF to Pulse Counting Relay       *
 * Converter.                                                            *
 *                                                                       *
 * Receives DTMF digits and activates T2/T3 and pulse counting relays    *
 * to their terminal count for the digit dialed.  This circuit's ground  *
 * comes from the Link B relay so that the converter is powered off when *
 * the link is idle.  This helps discriminate between first and second   *
 * dialed digits.  Additionally, the link E relay is monitored to        *
 * determine when it is ok to allow dialing again for conference calls.  *
 * The Link E relay is activated when the called station answers.  This  *
 * takes the state machine out of DIAL_STATE_DIALING_BLOCKED, returning  *
 * it to DIAL_STATE_IDLE so that further dialing is allowed.  In the     *
 * DIAL_STATE_IDLE state, dialing is inhibited if the E relay is active, *
 * which indicates that the called party is off-hook.                    *
 *                                                                       *
 * Arduino 1.8.57.0 or later with DxCore                                 *
 *                                                                       *
 *************************************************************************/

#define BAUD_RATE           115200
#define MS_PER_TICK         20
#define RELAY_HOLD_MS       100
#define POST_DIAL_MS        100
#define C1_DELAY_MS         60
#define COUNT_PER_MS        93.6
#define RELAY_HOLD_COUNT    (RELAY_HOLD_MS / MS_PER_TICK)
#define POST_DIAL_COUNT     (POST_DIAL_MS / MS_PER_TICK)
#define C1_DELAY_COUNT      (C1_DELAY_MS / MS_PER_TICK)

#define DIAL_STATE_IDLE             0
#define DIAL_STATE_WAIT_DTMF_DONE   1
#define DIAL_STATE_OPERATE_C1       2
#define DIAL_STATE_OPERATE_RELAYS   3
#define DIAL_STATE_DIALING_COMPLETE 4
#define DIAL_STATE_DIALING_BLOCKED  5

/* Pin assignments:
 * ref: https://github.com/SpenceKonde/DxCore/blob/master/megaavr/extras/DA28.md
 */

/* Inputs from MT8870 DTMF Receiver */
#define DTMF_Q0           0   /* PA0 */
#define DTMF_Q1           1   /* PA1 */
#define DTMF_Q2           2   /* PA2 */
#define DTMF_Q3           3   /* PA3 */
#define DTMF_StD          6   /* PA6 */

/* Outputs: Solid-State Relays driving 755A link relays, Low=On. */
#define SSR_T2            8   /* PC0 */
#define SSR_T3            9   /* PC1 */
#define SSR_C1            10  /* PC2 */

#define SSR_1_7           12  /* PD0 */
#define SSR_2_8           13  /* PD1 */
#define SSR_3_9           14  /* PD2 */
#define SSR_4_0           15  /* PD3 */
#define SSR_5_6           16  /* PD4 */
#define SSR_6             17  /* PD5 */
#define SSR_SPARE         19  /* PD7 */

#define SSR_1_7_B         (1 << 0)  /* PD0 */
#define SSR_2_8_B         (1 << 1)  /* PD1 */
#define SSR_3_9_B         (1 << 2)  /* PD2 */
#define SSR_4_0_B         (1 << 3)  /* PD3 */
#define SSR_5_6_B         (1 << 4)  /* PD4 */
#define SSR_6_B           (1 << 5)  /* PD5 */
#define SSR_SPARE_B       (1 << 7)  /* PD7 */

/* DTMF Digit to 755A Pulse Counting Relay Mapping */
const unsigned char units_relay_table[16] = {
    0,                    /* D (Not valid) */
    SSR_1_7_B,            /* 1 */
    SSR_2_8_B,            /* 2 */
    SSR_3_9_B,            /* 3 */
    SSR_4_0_B,            /* 4 */
    SSR_5_6_B,            /* 5 */
    SSR_5_6_B | SSR_6_B,  /* 6 */
    SSR_1_7_B | SSR_6_B,  /* 7 */
    SSR_2_8_B | SSR_6_B,  /* 8 */
    SSR_3_9_B | SSR_6_B,  /* 9 */
    SSR_4_0_B | SSR_6_B,  /* 0 */
    0,                    /* * (Not valid) */
    0,                    /* # (Not valid) */
    0,                    /* A (Not valid) */
    0,                    /* B (Not valid) */
    0                     /* C (Not valid) */
};

/* Inputs from 755A Link */
#define LINK_E            18  /* PD6 */

/* Output: Status LED, Low=On */
#define STATUS_LED        11  /* PIN_PC3 */

#define STATUS_LED_B      (1 << 3)

#define LED_ON(x)         VPORTC.OUT &= ~STATUS_LED_B;
#define LED_OFF(x)        VPORTC.OUT |=  STATUS_LED_B;

#define DIAL_IN_PROGRESS(x) \
  ((dtmf_dial_state != DIAL_STATE_IDLE) && \
   (dtmf_dial_state != DIAL_STATE_DIALING_BLOCKED))

const char          menu[] = "\n\rCommands:\n\r" \
                             "    w   - Dial 2x (tens digit)\n\r" \
                             "    h   - Dial 3x (tens digit)\n\r" \
                             "    0-9 - Dial (units digit)\n\r" \
                             "    a-c - Activate T2, T3, C1\n\r" \
                             "    d-g - Activate 1-7, 2-8, 3-9, 4-0\n\r" \
                             "    i-k - Activate 5-6, 6, Spare\n\r" \
                             "    r   - Release all relays\n\r";

volatile uint8_t dtmf_digit = 0;            /* DTMF Digit read by ISR */
uint8_t dtmf_digits[2] = { 0, 0 };          /* Storage for two dialed digits */
uint8_t digits_collected = 0;               /* Number of digits collected so far. */
bool link_e;
bool link_updated = false;
bool dtmf_updated = false;
bool pet_watchdog = true;
volatile uint32_t timer_tick = 0;
volatile uint8_t dtmf_dial_state = DIAL_STATE_IDLE;
static uint8_t dtmf_delay = 0;
unsigned long millis1, millis2, timedelta = 0;
char outstr[255];

#define wdt_reset() __asm__ __volatile__ ("wdr"::)  /* reset watchdog timer. */

/* Runs once during boot. */
void setup(void) {

  /* Initialize serial port */
  Serial.swap(1); /* Use PA4/PA5 for UART */
  Serial.begin(BAUD_RATE);

  VPORTC.OUT = 0xFF;
  VPORTD.OUT = 0xFF;

  /* Initialize GPIO Pins */
  pinMode (SSR_T2,      OUTPUT);
  pinMode (SSR_T3,      OUTPUT);
  pinMode (SSR_C1,      OUTPUT);
  pinMode (SSR_1_7,     OUTPUT);
  pinMode (SSR_2_8,     OUTPUT);
  pinMode (SSR_3_9,     OUTPUT);
  pinMode (SSR_4_0,     OUTPUT);
  pinMode (SSR_5_6,     OUTPUT);
  pinMode (SSR_6,       OUTPUT);
  pinMode (SSR_SPARE,   OUTPUT);
  pinMode (STATUS_LED,  OUTPUT);

  pinMode (DTMF_StD,    INPUT);
  pinMode (DTMF_Q0,     INPUT);
  pinMode (DTMF_Q1,     INPUT);
  pinMode (DTMF_Q2,     INPUT);
  pinMode (DTMF_Q3,     INPUT);
  pinMode (LINK_E,      INPUT_PULLUP);

  takeOverTCA0();
  TCA0.SINGLE.CTRLB = TCA_SINGLE_WGMODE_NORMAL_gc;
  TCA0.SINGLE.EVCTRL &= ~(TCA_SINGLE_CNTEI_bm);
  TCA0.SINGLE.PER = MS_PER_TICK * COUNT_PER_MS;
  TCA0.SINGLE.INTCTRL = TCA_SINGLE_OVF_bm; /* Enable timer overflow interrupt */
  TCA0.SINGLE.CTRLA = TCA_SINGLE_CLKSEL_DIV256_gc | TCA_SINGLE_ENABLE_bm;

  attachInterrupt(digitalPinToInterrupt(LINK_E), link_isr,   CHANGE);
  attachInterrupt(digitalPinToInterrupt(DTMF_StD),    DTMF_isr,   RISING);

  Serial.print("Western Electric 755A Crossbar PBX DTMF Converter v1.0\r\n");
  Serial.print("(c) 2023 Howard M. Harte - github.com/hharte/we755a_dtmf\r\n");

  snprintf(outstr, sizeof(outstr), "\r\nWE755A> ");
  Serial.print(outstr);
}

/* Main loop: Process serial console input */
void loop() {
  uint8_t choice;

  if (pet_watchdog) {
    wdt_reset();  /* Pet watchdog timer. */
  }

  if (Serial.available() > 0) {
    /* Read character from the serial port. */
    choice = Serial.read();
    Serial.write(choice);

    switch(choice) {
      case '?':
        Serial.print(menu);
        break;
      case 'w':
      case 'W':
        dtmf_digits[0] = 2;
        dtmf_digits[1] = 0;
        dtmf_dial_state = DIAL_STATE_OPERATE_C1;
        LED_ON();
        Serial.print("\r\nDial 2 (tens)\r\n");
        while (DIAL_IN_PROGRESS());
        LED_OFF();
        dtmf_updated = 0;
        break;
      case 'h':
      case 'H':
        dtmf_digits[0] = 3;
        dtmf_digits[1] = 0;
        dtmf_dial_state = DIAL_STATE_OPERATE_C1;
        LED_ON();
        Serial.print("\r\nDial 3 (tens)\r\n");
        while (DIAL_IN_PROGRESS());
        LED_OFF();
        dtmf_updated = 0;
        break;
      case '0':
      case '1':
      case '2':
      case '3':
      case '4':
      case '5':
      case '6':
      case '7':
      case '8':
      case '9': {
        uint8_t r = choice - '0';

        sprintf(outstr, "\r\nDial %d (units)\r\n", r);
        Serial.print(outstr);
        if (r == 0) r = 10; /* '0' is 10 for the 8870. */
        dtmf_digits[1] = r;
        dtmf_dial_state = DIAL_STATE_OPERATE_C1;
        LED_ON();
        while (DIAL_IN_PROGRESS());
        LED_OFF();
        break;
      }
      case 'a':
      case 'A':
      {
        digitalWrite(SSR_T2, LOW);
        Serial.print("\r\nActivate T2\r\n");
        break;
      }
      case 'b':
      case 'B':
      {
        digitalWrite(SSR_T3, LOW);
        Serial.print("\r\nActivate T3\r\n");
        break;
      }
      case 'c':
      case 'C':
      {
        digitalWrite(SSR_C1, LOW);
        Serial.print("\r\nActivate C1\r\n");
        break;
      }
      case 'd':
      case 'D':
      {
        digitalWrite(SSR_1_7, LOW);
        Serial.print("\r\nActivate 1-7\r\n");
        break;
      }
      case 'e':
      case 'E':
      {
        digitalWrite(SSR_2_8, LOW);
        Serial.print("\r\nActivate 2-8\r\n");
        break;
      }
      case 'f':
      case 'F':
      {
        digitalWrite(SSR_3_9, LOW);
        Serial.print("\r\nActivate 3-9\r\n");
        break;
      }
      case 'g':
      case 'G':
      {
        digitalWrite(SSR_4_0, LOW);
        Serial.print("\r\nActivate 4-0\r\n");
        break;
      }
      case 'i':
      case 'I':
      {
        digitalWrite(SSR_5_6, LOW);
        Serial.print("\r\nActivate 5-6\r\n");
        break;
      }
      case 'j':
      case 'J':
      {
        digitalWrite(SSR_6, LOW);
        Serial.print("\r\nActivate 6\r\n");
        break;
      }
      case 'k':
      case 'K':
      {
        digitalWrite(SSR_SPARE, LOW);
        Serial.print("\r\nActivate Spare SSR\r\n");
        break;
      }
      case 'r':
      case 'R':
      {
        digitalWrite(SSR_T2,    HIGH);
        digitalWrite(SSR_T3,    HIGH);
        digitalWrite(SSR_C1,    HIGH);
        digitalWrite(SSR_1_7,   HIGH);
        digitalWrite(SSR_2_8,   HIGH);
        digitalWrite(SSR_3_9,   HIGH);
        digitalWrite(SSR_4_0,   HIGH);
        digitalWrite(SSR_5_6,   HIGH);
        digitalWrite(SSR_6,     HIGH);
        digitalWrite(SSR_SPARE, HIGH);
        Serial.print("\r\nReleased all relays\r\n");
        break;
      }
      case '\r':
      case '\n':
        break;
      default:
        Serial.print("\r\nInvalid choice.\r\n");
        break;
    }

    snprintf(outstr, sizeof(outstr), "\r\nWE755A> ");
    Serial.print(outstr);
  }

  if (dtmf_updated == 1) {
    sprintf(outstr, "Dialing x%d%d\r\n", dtmf_digits[0], (dtmf_digits[1] == 10) ? 0 : dtmf_digits[1]);
    dtmf_updated = 0;
    Serial.print(outstr);
  }
  if (link_updated == 1) {
    sprintf(outstr, "Link E relay changed to %s\r\n", link_e == 1 ? "Operated" : "Released");
    link_updated = 0;
    Serial.print(outstr);
  }
}

/* Process low to high transitions on the MT8870 StD input. */
void DTMF_isr(void) {

  if (digitalRead(DTMF_StD) == 1) {
    LED_ON();
    dtmf_digit = VPORTA.IN & 0x0F;
  }
}

/* Process high to low transitions on the LINK_E line. */
void link_isr(void) {
  bool link_prev = link_e;
  if (digitalRead(LINK_E) == 0) {
    link_e = true;
  } else {
    link_e = false;
  }

  if (link_prev != link_e) {
    link_updated = true;
  }
}

/* TCA0 Timer Tick Interrupt */
ISR(TCA0_OVF_vect) {
  TCA0.SINGLE.INTFLAGS  = TCA_SINGLE_OVF_bm; /* Clear interrupt flags */
  timer_tick += 1;

  millis2 = millis1;
  millis1 = millis();
  timedelta = millis1 - millis2;

#ifdef BLINK_LED
  if (timer_tick & 0x40) {
    LED_ON();
  } else {
    LED_OFF();
  }
#endif /* BLINK_LED */

  switch(dtmf_dial_state) {
    case DIAL_STATE_IDLE:
      /* Waiting for DTMF from Link. */
      LED_OFF();

      if (digitalRead(LINK_E) == 0) {
        /* When LINK E relay is active, the called station has answered,
         * do not allow dialing until the called party hangs up.
         */
        dtmf_digit = 0;
        break;
      }
      if (dtmf_digit > 0) {
          dtmf_dial_state = DIAL_STATE_WAIT_DTMF_DONE;
          dtmf_digits[digits_collected] = dtmf_digit;
          if (digits_collected == 0) {
            switch (dtmf_digit) {
              case 3:
                /* Operate T3. */
                digitalWrite(SSR_T3, LOW);
              case 10:
              case 2:
              case 8:
              case 9:
                /* Operate T2 to break dialtone. */
                digitalWrite(SSR_T2, LOW);
                break;
              default:
                break;
            }
          }
          dtmf_digit = 0;
      }
      break;
    case DIAL_STATE_WAIT_DTMF_DONE:
      /* Wait in this state until DTMFx_StD is de-asserted. */

      if (digitalRead(DTMF_StD) == 0) {
        digits_collected++;
        LED_ON();
        if (digits_collected == 1) {
          digitalWrite(SSR_T2, HIGH);
          switch (dtmf_digits[0]) {
            case 10: /* Operator */
              dtmf_digits[0] = 2;
              dtmf_digits[1] = 10;
              digits_collected = 2;
              break;
            case 2: /* STA 2x */
            case 3: /* STA 3x */
              dtmf_dial_state = DIAL_STATE_IDLE;
              break;
            case 8: /* Tie Lines: x26/x27 */
              dtmf_digits[0] = 2;
              dtmf_digits[1] = 6;
              digits_collected = 2;
              break;
            case 9: /* Tie Lines: x36/x37 */
              dtmf_digits[0] = 3;
              dtmf_digits[1] = 6;
              digits_collected = 2;
              break;
            case 1: /* Ignore these digits... */
            case 4:
            case 5:
            case 6:
            case 7:
            default:
              dtmf_digits[0] = 0;
              digits_collected = 0;
              dtmf_dial_state = DIAL_STATE_IDLE;
          }
        }
        if (digits_collected == 2) {
          dtmf_dial_state = DIAL_STATE_OPERATE_C1;
        }
      }
      break;
    case DIAL_STATE_OPERATE_C1:
      dtmf_delay++;
      if (dtmf_digits[1] > 0) {
        /* Operate C1 relay */
        digitalWrite(SSR_C1, LOW);
      }

      if (dtmf_delay == C1_DELAY_COUNT) {
        dtmf_delay = 0;
        dtmf_dial_state = DIAL_STATE_OPERATE_RELAYS;
      }
      break;
    case DIAL_STATE_OPERATE_RELAYS:
      dtmf_delay++;
      if (dtmf_delay == POST_DIAL_COUNT) {
        dtmf_delay = 0;
        dtmf_updated = 1;

        /* Operate the 755A Tens Relays T2, T3 */
        switch (dtmf_digits[0]) {
          case 3: /* 3x */
            digitalWrite(SSR_T3, LOW);
            /* Fall through */
          case 2: /* 2x */
            digitalWrite(SSR_T2, LOW);
            break;
          default:
            break;
        }

        if (dtmf_digits[1] > 0) {
          /* Operate Units relays */
          VPORTD.OUT &= ~(units_relay_table[dtmf_digits[1]]);
        }
        dtmf_dial_state = DIAL_STATE_DIALING_COMPLETE;
      }
      break;
    case DIAL_STATE_DIALING_COMPLETE:
      dtmf_delay++;
      if (dtmf_delay == RELAY_HOLD_COUNT) {
        dtmf_delay = 0;

        /* Release T2 and T3 relays */
        digitalWrite(SSR_T2, HIGH);
        digitalWrite(SSR_T3, HIGH);

        /* Release units relays */
        VPORTD.OUT |= units_relay_table[dtmf_digits[1]];

        /* Release C1 relay */
        digitalWrite(SSR_C1, HIGH);

        /* Block dialing until the called station answers, and then goes back on-hook. */
        dtmf_dial_state = DIAL_STATE_DIALING_BLOCKED;
      }
      break;
    case DIAL_STATE_DIALING_BLOCKED:
      /* Unblock dialing when the called station answers. */
      if (digitalRead(LINK_E) == 0) {
        digits_collected = 0;
        dtmf_digits[0] = 0;
        dtmf_digits[1] = 0;
        dtmf_dial_state = DIAL_STATE_IDLE;
      }
      break;
    default: /* Invalid state, go back to idle. */
      dtmf_dial_state = DIAL_STATE_IDLE;
      break;
  }
}

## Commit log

2023-06-25 Initial revision.
    [we755a_dtmf-B_Cu.gbr, we755a_dtmf-B_Mask.gbr, we755a_dtmf-B_Silkscreen.gbr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]
2023-06-25 755A DTMF Firmware, bench tested.
    * LED behavior:
    - Light at beginning of DTMF tone.
    - Out while idle (wait for DTMF Done)
    - On while processing relays.
    * Timing: 100ms post dial delay (before T2/T3)
    200ms hold for T2/T3, units relays, and C1.
2023-07-04 Update PCB to Rev2: No functional changes.
    * Rev 1 and Rev 2 PCBs are identical except for the silkscreen.
    * Rename LINK_B to LINK_E on schematic and layout.
    * Correct value of C1 on schematic.
    [we755a_dtmf-B_Cu.gbr, we755a_dtmf-B_Mask.gbr, we755a_dtmf-B_Silkscreen.gbr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]
2024-03-23 Update to KiCAD 8.0.1.
    [we755a_dtmf-B_Cu.gbr, we755a_dtmf-B_Mask.gbr, we755a_dtmf-B_Silkscreen.gbr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]
2024-04-14 Issue 3: Smaller board. * Smaller board. * Jumper options for DTMF converter and station concentrator.
    [we755a_dtmf-B_Cu.gbr, we755a_dtmf-B_Mask.gbr, we755a_dtmf-B_Silkscreen.gbr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]
2024-04-21 Update cover for Iss 3.
    [we755a_dtmf_cover.FCStd, we755a_dtmf_cover.stl]
2024-06-02 Issue 4: Change fuses to PTCs.
    [we755a_dtmf-B_Cu.gbr, we755a_dtmf-B_Mask.gbr, we755a_dtmf-B_Silkscreen.gbr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]
2024-06-16 Change C6 from electrolytic to ceramic.
    [we755a_dtmf-B_Cu.gbr, we755a_dtmf-B_Mask.gbr, we755a_dtmf-B_Silkscreen.gbr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]
